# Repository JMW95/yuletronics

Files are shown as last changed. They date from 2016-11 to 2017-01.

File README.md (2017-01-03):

# Yuletronics: Electronics Club Project Michaelmas 2016

A small electronic Christmas decoration with a 5x5 pixel LED screen.

Scrolls festive messages across the screen, and plays Flappy Bird!

Firmware written in C using ChibiOS for the STM32F042F6P6 microcontroller.
PCB designed in KiCAD. Download it [here](http://kicad-pcb.org/).

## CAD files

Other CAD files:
pcb/gerbers/yuletronics-F.Paste.dxf

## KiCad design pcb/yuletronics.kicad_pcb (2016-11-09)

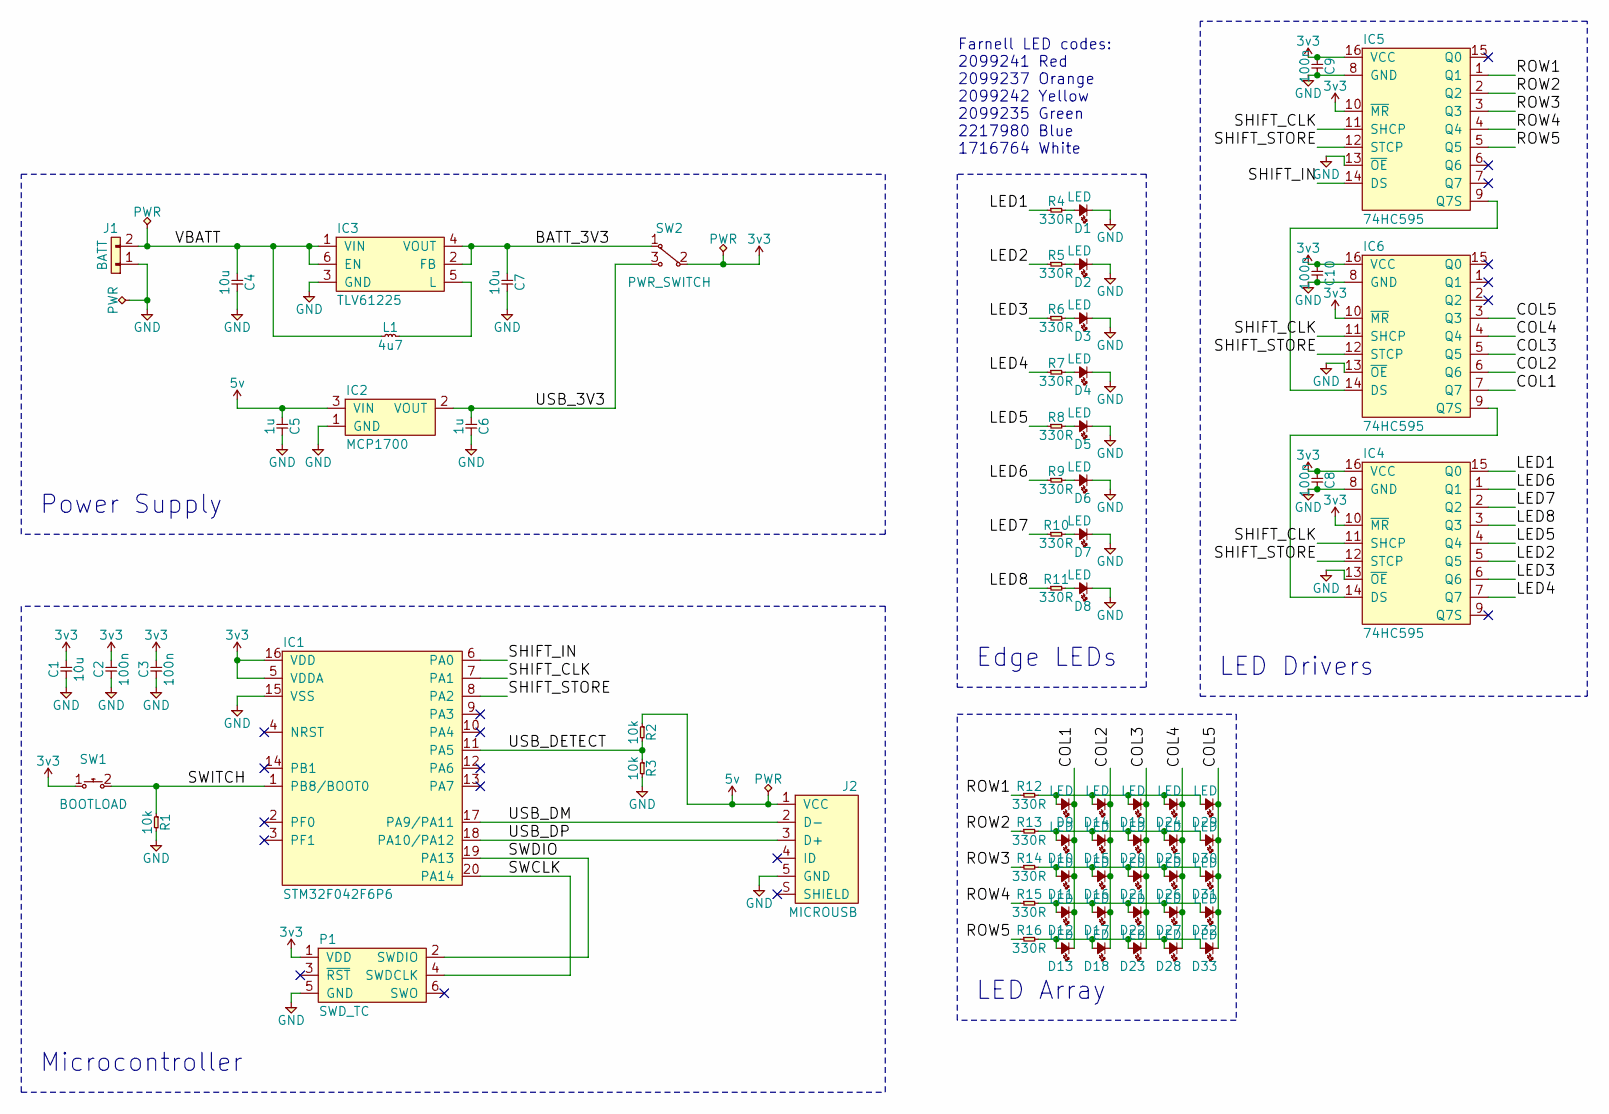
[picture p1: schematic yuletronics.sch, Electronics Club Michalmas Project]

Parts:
C1, C4, C7: 10u; 0603; Farnell 2494230
C2, C3, C8, C9, C10: 100n; 0603; Farnell 1759038
C5, C6: 1u; 0603; Farnell 1759399
D1, D8: LED; 0805-LED; Farnell 2099242
D2, D5: LED; 0805-LED; Farnell 2217980
D3: LED; 0805-LED; Farnell 2099235
D4: LED; KPA-1606; Farnell 2290355
D6: LED; KPA-1606; Farnell 2290360
D7: LED; 0805-LED; Farnell 2099241
D9, D10, D11, D12, D13, D14, D15, D16, D17, D18, D19, D20, D21, D22, D23, D24, D25, D26, D27, D28, D29, D30, D31, D32, D33: LED; KPT-1608; Farnell 2099221
IC1: STM32F042F6P6; TSSOP-20; Farnell 2469549
IC2: MCP1700; SOT-23; Farnell 1296592
IC3: TLV61225; SC-70-6; Farnell 2492362
IC4, IC5, IC6: 74HC595; TSSOP-16; Farnell 2425499
J1: BATT; AAA_HOLDER; Farnell 1702632
J2: MICROUSB; MICROUSB_MOLEX_47589-0001; Farnell 1568023
L1: 4u7; 2016M; Farnell 2616849
P1: SWD_TC; TC2030-NL
R1, R2, R3: 10k; 0603; Farnell 9330399
R4, R5, R6, R7, R8, R9, R10, R11, R12, R13, R14, R15, R16: 330R; 0603; Farnell 9331018
SW1: BOOTLOAD; MOM_SWITCH; Farnell 2056809
SW2: PWR_SWITCH; SPDT_SWITCH; Farnell 1201430

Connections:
3v3: C1.2, C2.2, C3.2, C8.1, C9.1, C10.1, IC1.5 (VDDA), IC1.16 (VDD), IC4.10 (~MR), IC4.16 (VCC), IC5.10 (~MR), IC5.16 (VCC), IC6.10 (~MR), IC6.16 (VCC), P1.1 (VDD), SW1.1, SW2.2
5v: C5.1, IC2.3 (VIN), J2.1 (VCC), R2.1
/BATT_3V3: C7.1, IC3.2 (FB), IC3.4 (VOUT), SW2.1
/COL1: D9.1, D10.1, D11.1, D12.1, D13.1, IC6.7 (Q7)
/COL2: D14.1, D15.1, D16.1, D17.1, D18.1, IC6.6 (Q6)
/COL3: D19.1, D20.1, D21.1, D22.1, D23.1, IC6.5 (Q5)
/COL4: D24.1, D25.1, D26.1, D27.1, D28.1, IC6.4 (Q4)
/COL5: D29.1, D30.1, D31.1, D32.1, D33.1, IC6.3 (Q3)
/LED1: IC4.15 (Q0), R4.1
/LED2: IC4.5 (Q5), R5.1
/LED3: IC4.6 (Q6), R6.1
/LED4: IC4.7 (Q7), R7.1
/LED5: IC4.4 (Q4), R8.1
/LED6: IC4.1 (Q1), R9.1
/LED7: IC4.2 (Q2), R10.1
/LED8: IC4.3 (Q3), R11.1
/ROW1: IC5.1 (Q1), R12.1
/ROW2: IC5.2 (Q2), R13.1
/ROW3: IC5.3 (Q3), R14.1
/ROW4: IC5.4 (Q4), R15.1
/ROW5: IC5.5 (Q5), R16.1
/SHIFT_CLK: IC1.7 (PA1), IC4.11 (SHCP), IC5.11 (SHCP), IC6.11 (SHCP)
/SHIFT_IN: IC1.6 (PA0), IC5.14 (DS)
/SHIFT_STORE: IC1.8 (PA2), IC4.12 (STCP), IC5.12 (STCP), IC6.12 (STCP)
/SWCLK: IC1.20 (PA14), P1.4 (SWDCLK)
/SWDIO: IC1.19 (PA13), P1.2 (SWDIO)
/SWITCH: IC1.1 (PB8/BOOT0), R1.1, SW1.2
/USB_3V3: C6.1, IC2.2 (VOUT), SW2.3
/USB_DETECT: IC1.11 (PA5), R2.2, R3.1
/USB_DM: IC1.17 (PA9/PA11), J2.2 (D-)
/USB_DP: IC1.18 (PA10/PA12), J2.3 (D+)
/VBATT: C4.1, IC3.1 (VIN), IC3.6 (EN), J1.2, L1.1
GND: C1.1, C2.1, C3.1, C4.2, C5.2, C6.2, C7.2, C8.2, C9.2, C10.2, D1.1, D2.1, D3.1, D4.1, D5.1, D6.1, D7.1, D8.1, IC1.15 (VSS), IC2.1 (GND), IC3.3 (GND), IC4.8 (GND), IC4.13 (~OE), IC5.8 (GND), IC5.13 (~OE), IC6.8 (GND), IC6.13 (~OE), J1.1, J2.5 (GND), P1.5 (GND), R1.2, R3.2
unnamed: D1.2, R4.2
unnamed: D2.2, R5.2
unnamed: D3.2, R6.2
unnamed: D4.2, R7.2
unnamed: D5.2, R8.2
unnamed: D6.2, R9.2
unnamed: D7.2, R10.2
unnamed: D8.2, R11.2
unnamed: D10.2, D15.2, D20.2, D25.2, D30.2, R13.2
unnamed: D11.2, D16.2, D21.2, D26.2, D31.2, R14.2
unnamed: D12.2, D17.2, D22.2, D27.2, D32.2, R15.2
unnamed: D13.2, D18.2, D23.2, D28.2, D33.2, R16.2
unnamed: D9.2, D14.2, D19.2, D24.2, D29.2, R12.2
unnamed: IC3.5 (L), L1.2
unnamed: IC4.14 (DS), IC6.9 (Q7S)
unnamed: IC5.9 (Q7S), IC6.14 (DS)

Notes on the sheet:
Power Supply
Microcontroller
Edge LEDs
Farnell LED codes: 2099241 Red 2099237 Orange 2099242 Yellow 2099235 Green 2217980 Blue 1716764 White
LED Drivers
LED Array

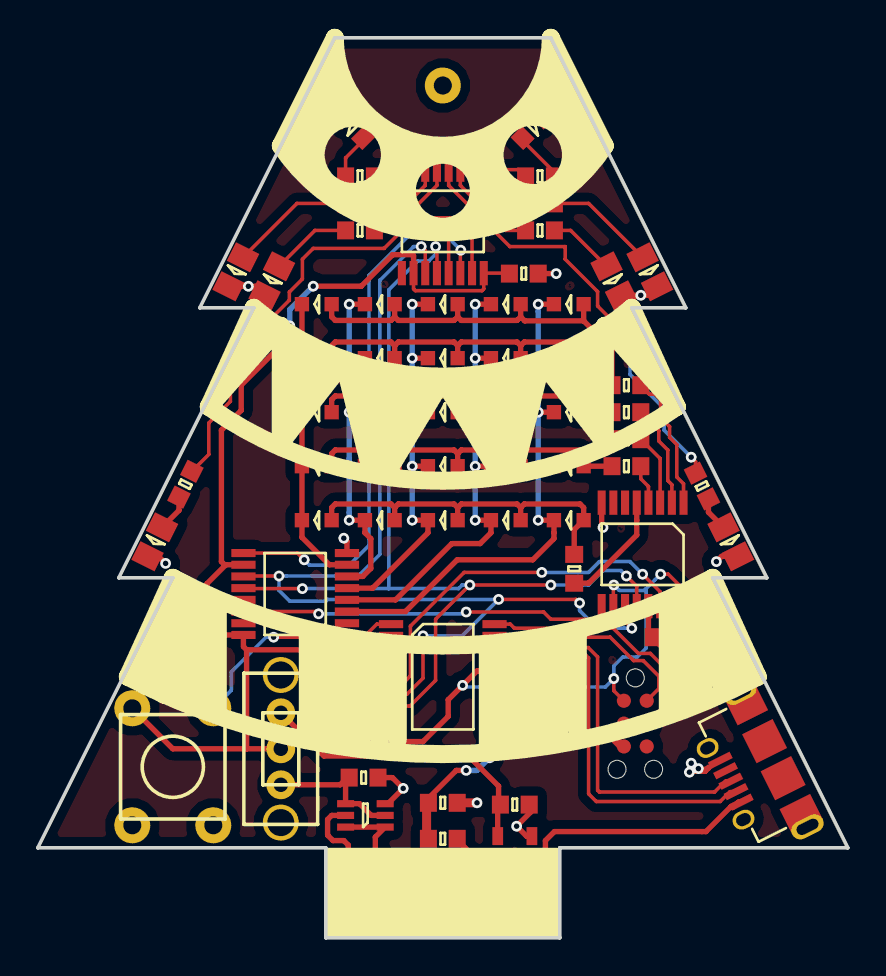
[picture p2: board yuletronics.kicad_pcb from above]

Board: 2 copper layers, 45.0 x 50.0 mm, 71 parts (1 on the bottom side), 49 nets.

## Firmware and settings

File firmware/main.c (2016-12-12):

#include "yuletronics_config.h"

#include "ch.h"
#include "hal.h"
#include "chprintf.h"

#include "rand.h"
#include "display.h"
#include "animations.h"

#if EASTER_EGG
    #include "easter_egg.h"
#endif

#if USE_USB
    #include "usb.h"
#endif

static bool easterEggMode = false;
static uint32_t mode = 0;

static const char *messages[] = {
    "MERRY CHRISTMAS",
    "HO HO HO",
    "JINGLE BELLS",
    "SANTA CLAUS",
    "SLEIGH BELLS RING",
    "DECK THE HALLS",
};
#define NUM_MESSAGES    6

// Constantly redraw the screen
static THD_WORKING_AREA(waScreenRefresh, 128);
THD_FUNCTION(screen_refresh, arg){
    (void)arg;
    chRegSetThreadName("Screen refresh");
    while(TRUE){
        display_show();
    }
}

// Randomly turn on and off the edge LEDs
static THD_WORKING_AREA(waLEDS, 64);
THD_FUNCTION(leds_update, arg){
    (void)arg;
    chRegSetThreadName("LEDs");
    while(TRUE){
        int led = rand() % 8;
        if(rand() & 1){
            led_turn_on(led);
        }else{
            led_turn_off(led);
        }
        chThdSleepMilliseconds(250 + (rand() % 512));
    }
}

#if EASTER_EGG
// Launch the easter egg if the button is held
static THD_WORKING_AREA(waEasterEgg, 128);
THD_FUNCTION(easter_egg, arg){
    (void)arg;
    chRegSetThreadName("Easter Egg");
    int heldCounter = 0;
    while(TRUE){
        if(palReadLine(LINE_SWITCH)){
            heldCounter++;
            if(heldCounter == 20){ // If held for 2 seconds
                easterEggMode = true;

                easter_egg_start(); // Run the easter egg

                mode = 3; // Play an animation
                display_clear();
                display_scroll_text("");

                easterEggMode = false;
            }
        }else{
            heldCounter = 0;
        }
        chThdSleep(100);
    }
}
#endif

// Write some text on the screen
static THD_WORKING_AREA(waText, 256);
THD_FUNCTION(text_update, arg){
    (void)arg;
    chRegSetThreadName("Modes");
    
    uint32_t delay = 60;
    uint8_t messagenum = 0;
    uint8_t animnum = 0;
    
    display_scroll_text(messages[messagenum]);
    display_set_anim(animnum);
    
    while(TRUE){
        if(!easterEggMode){
            switch(mode){
                case 0: // Scroll text
                    delay = 80;
                    if(display_scroll()){
                        display_scroll_text(""); // Blank the display
                        mode = 3;
                    }
                    break;
                case 1: // Choose another message
                    messagenum += 1;
                    if(messagenum >= NUM_MESSAGES){
                        messagenum = 0;
                    }
                    display_scroll_text(messages[messagenum]);
#if USE_USB
                    if(serusbcfg.usbp->state == USB_ACTIVE){
                        chprintf((BaseSequentialStream *)&SDU1, messages[messagenum]);
                        chprintf((BaseSequentialStream *)&SDU1, "\r\n");
                    }
#endif
                    mode = 4;
                    break;
                case 2: // Display an animation
                    delay = 100;
                    if(display_anim()){
                        display_clear();
                        mode = 1;
                    }
                    break;
                case 3: // Choose another animation
                    animnum += 1;
                    if(animnum >= NUM_ANIMS){
                        animnum = 0;
                    }
                    display_set_anim(animnum);
                    mode = 5;
                    break;
                case 4: // Check for low-power mode then continue
                case 5:
#if AUTO_ANIMATIONS
                    delay = 3000;
                    {
#else
                    delay = 200;
                    if(palReadLine(LINE_SWITCH)){
#endif
                        if(mode == 4){
                            mode = 0;
                        }else{
                            mode = 2;
                        }
                    }
                    break;
            }
            chThdSleepMilliseconds(delay);
        }else{
            chThdSleepMilliseconds(1000);
        }
    }
}

#if USE_USB
// Read the USB port and display text
static THD_WORKING_AREA(waSerial, 256);
THD_FUNCTION(serial_read, arg){
    (void)arg;
    chRegSetThreadName("Serial");
    static char buf[255];
    uint32_t count = 0;
    int read = 0;
    uint8_t c;
    while(TRUE){
        read = chSequentialStreamRead((BaseSequentialStream *)&SDU1,
                                      &c, 1);
        if(read > 0){
            if(c == '\n'){
                buf[count] = 0;
                count = 0;
                display_scroll_text(buf);
                mode = 0;
                while(mode == 0){
                    chThdSleepMilliseconds(10);
                }
            }else{
                buf[count] = (char)c;
                count++;
                if(count == sizeof(buf)){
                    buf[count-1] = 0;
                    display_scroll_text(buf);
                    mode = 0;
                    while(mode == 0){
                        chThdSleepMilliseconds(10);
                    }
                }
            }
        }
        chThdSleepMilliseconds(1);
    }
}
#endif

int main(void) {
    /* Allow debug access during STOP/STANDBY */
    DBGMCU->CR |= DBGMCU_CR_DBG_STOP;

    halInit();
    // Remap the USB pins to the physical pins
    SYSCFG->CFGR1 |= SYSCFG_CFGR1_PA11_PA12_RMP;
    chSysInit();
    
    display_init();

    //TODO: seed the RNG using a few ADC reads?

    chThdCreateStatic(waScreenRefresh, sizeof(waScreenRefresh), NORMALPRIO,
                    screen_refresh, NULL);
    chThdCreateStatic(waLEDS, sizeof(waLEDS), NORMALPRIO,
                    leds_update, NULL);
    chThdCreateStatic(waText, sizeof(waText), NORMALPRIO,
                    text_update, NULL);
#if EASTER_EGG
    chThdCreateStatic(waEasterEgg, sizeof(waEasterEgg), NORMALPRIO,
                    easter_egg, NULL);
#endif
#if USE_USB
    chThdCreateStatic(waSerial, sizeof(waSerial), NORMALPRIO,
                    serial_read, NULL);

    sduObjectInit(&SDU1);

    sduStart(&SDU1, &serusbcfg);

    /*
    * Activates the USB driver and then the USB bus pull-up on D+.
    * Note, a delay is inserted in order to not have to disconnect the cable
    * after a reset.
    */
    usbDisconnectBus(serusbcfg.usbp);
    chThdSleepMilliseconds(1500);
    usbStart(serusbcfg.usbp, &usbcfg);
    usbConnectBus(serusbcfg.usbp);
#endif

    // Allow idle sleep to take over
    chThdSleep(TIME_INFINITE);

    return 0;
}

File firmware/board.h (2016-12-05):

/*
    ChibiOS - Copyright (C) 2006..2016 Giovanni Di Sirio
    Licensed under the Apache License, Version 2.0 (the "License");
    you may not use this file except in compliance with the License.
    You may obtain a copy of the License at
    http://www.apache.org/licenses/LICENSE-2.0
    Unless required by applicable law or agreed to in writing, software
    distributed under the License is distributed on an "AS IS" BASIS,
    WITHOUT WARRANTIES OR CONDITIONS OF ANY KIND, either express or implied.
    See the License for the specific language governing permissions and
    limitations under the License.
*/

/*
    Generated by gen-board.h.py based on board.yaml
*/

#ifndef _BOARD_H_
#define _BOARD_H_


/*
    Setup for Yuletronics
*/

/*
    Board identifier
*/
#define BOARD_Yuletronics
#define BOARD_NAME                     "Yuletronics"

/*
    Board oscillators-related settings.
*/
#if !defined(STM32_LSECLK)
#define STM32_LSECLK                   0U
#endif

#if !defined(STM32_HSECLK)
#define STM32_HSECLK                   0U
#endif

/*
    Board voltages
    Required for performance limits calculation.
*/
#define STM32_VDD                      330U

/*
    MCU type as defined in the ST header.
*/
#define STM32F042x6

/*
    IO pins assignments.
*/

#define GPIOA_SHIFT_DATA               0U
#define GPIOA_SHIFT_CLK                1U
#define GPIOA_SHIFT_LATCH              2U
#define GPIOA_PIN3                     3U
#define GPIOA_PIN4                     4U
#define GPIOA_USB_DETECT               5U
#define GPIOA_PIN6                     6U
#define GPIOA_PIN7                     7U
#define GPIOA_PIN8                     8U
#define GPIOA_PIN9                     9U
#define GPIOA_PIN10                    10U
#define GPIOA_PIN11                    11U
#define GPIOA_PIN12                    12U
#define GPIOA_SWDIO                    13U
#define GPIOA_SWDCLK                   14U
#define GPIOA_PIN15                    15U

#define GPIOB_PIN0                     0U
#define GPIOB_PIN1                     1U
#define GPIOB_PIN2                     2U
#define GPIOB_PIN3                     3U
#define GPIOB_PIN4                     4U
#define GPIOB_PIN5                     5U
#define GPIOB_PIN6                     6U
#define GPIOB_PIN7                     7U
#define GPIOB_SWITCH                   8U
#define GPIOB_PIN9                     9U
#define GPIOB_PIN10                    10U
#define GPIOB_PIN11                    11U
#define GPIOB_PIN12                    12U
#define GPIOB_PIN13                    13U
#define GPIOB_PIN14                    14U
#define GPIOB_PIN15                    15U

#define GPIOC_PIN0                     0U
#define GPIOC_PIN1                     1U
#define GPIOC_PIN2                     2U
#define GPIOC_PIN3                     3U
#define GPIOC_PIN4                     4U
#define GPIOC_PIN5                     5U
#define GPIOC_PIN6                     6U
#define GPIOC_PIN7                     7U
#define GPIOC_PIN8                     8U
#define GPIOC_PIN9                     9U
#define GPIOC_PIN10                    10U
#define GPIOC_PIN11                    11U
#define GPIOC_PIN12                    12U
#define GPIOC_PIN13                    13U
#define GPIOC_PIN14                    14U
#define GPIOC_PIN15                    15U

#define GPIOD_PIN0                     0U
#define GPIOD_PIN1                     1U
#define GPIOD_PIN2                     2U
#define GPIOD_PIN3                     3U
#define GPIOD_PIN4                     4U
#define GPIOD_PIN5                     5U
#define GPIOD_PIN6                     6U
#define GPIOD_PIN7                     7U
#define GPIOD_PIN8                     8U
#define GPIOD_PIN9                     9U
#define GPIOD_PIN10                    10U
#define GPIOD_PIN11                    11U
#define GPIOD_PIN12                    12U
#define GPIOD_PIN13                    13U
#define GPIOD_PIN14                    14U
#define GPIOD_PIN15                    15U

#define GPIOF_PIN0                     0U
#define GPIOF_PIN1                     1U
#define GPIOF_PIN2                     2U
#define GPIOF_PIN3                     3U
#define GPIOF_PIN4                     4U
#define GPIOF_PIN5                     5U
#define GPIOF_PIN6                     6U
#define GPIOF_PIN7                     7U
#define GPIOF_PIN8                     8U
#define GPIOF_PIN9                     9U
#define GPIOF_PIN10                    10U
#define GPIOF_PIN11                    11U
#define GPIOF_PIN12                    12U
#define GPIOF_PIN13                    13U
#define GPIOF_PIN14                    14U
#define GPIOF_PIN15                    15U

/*
    IO lines assignments.
*/
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

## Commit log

2016-11-01 Add LED array
    [yuletronics.kicad_pcb, yuletronics.sch]
2016-11-09 Add gerbers, fix DRC
    [yuletronics-B.Cu.gbl, yuletronics-B.Mask.gbs, yuletronics-B.SilkS.gbo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]
2016-11-14 Add shiftreg driver
2016-11-14 Fix board and mcu setup
    [board.h, mcuconf.h]
2016-11-18 Fix initial state of outputs
    [board.h]
2016-11-30 Add stencil dxf
    [yuletronics-F.Paste.dxf]
2016-12-01 Add software PWM
2016-12-01 Change pwm_tick to a single value
2016-12-05 Add switch to board.yaml/.h
2016-12-06 Add USB Serial printing
2016-12-07 Reduce code footprint by disabling ChibiOS features
2016-12-12 Change to ticked mode to reduce power draw a bit
2016-12-12 Add low-power mode
